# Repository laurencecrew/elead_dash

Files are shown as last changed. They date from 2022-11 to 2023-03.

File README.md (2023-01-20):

# elead_dash

Dash module for Honda Lead scooter electric conversion.

Based on STM32Duino for STM32F103C8T6

Design includes:
- Votol EM150SP 'CANbus' controller
- Daly R25A-GI02 BMS CANBus x 2
- SSD1306 OLED 64x48 0.66" SPI x 2
- Original fuel gauge driven by H-bridge / PWM
- See also, elead_lighting for tail light module

See 'Hardware' folder for:
- Bike wiring diagram
- PCB schematics
- Eagle files
- PCB CAM outputs

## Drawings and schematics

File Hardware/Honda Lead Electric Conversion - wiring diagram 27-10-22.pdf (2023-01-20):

## TO BATTERIES

1

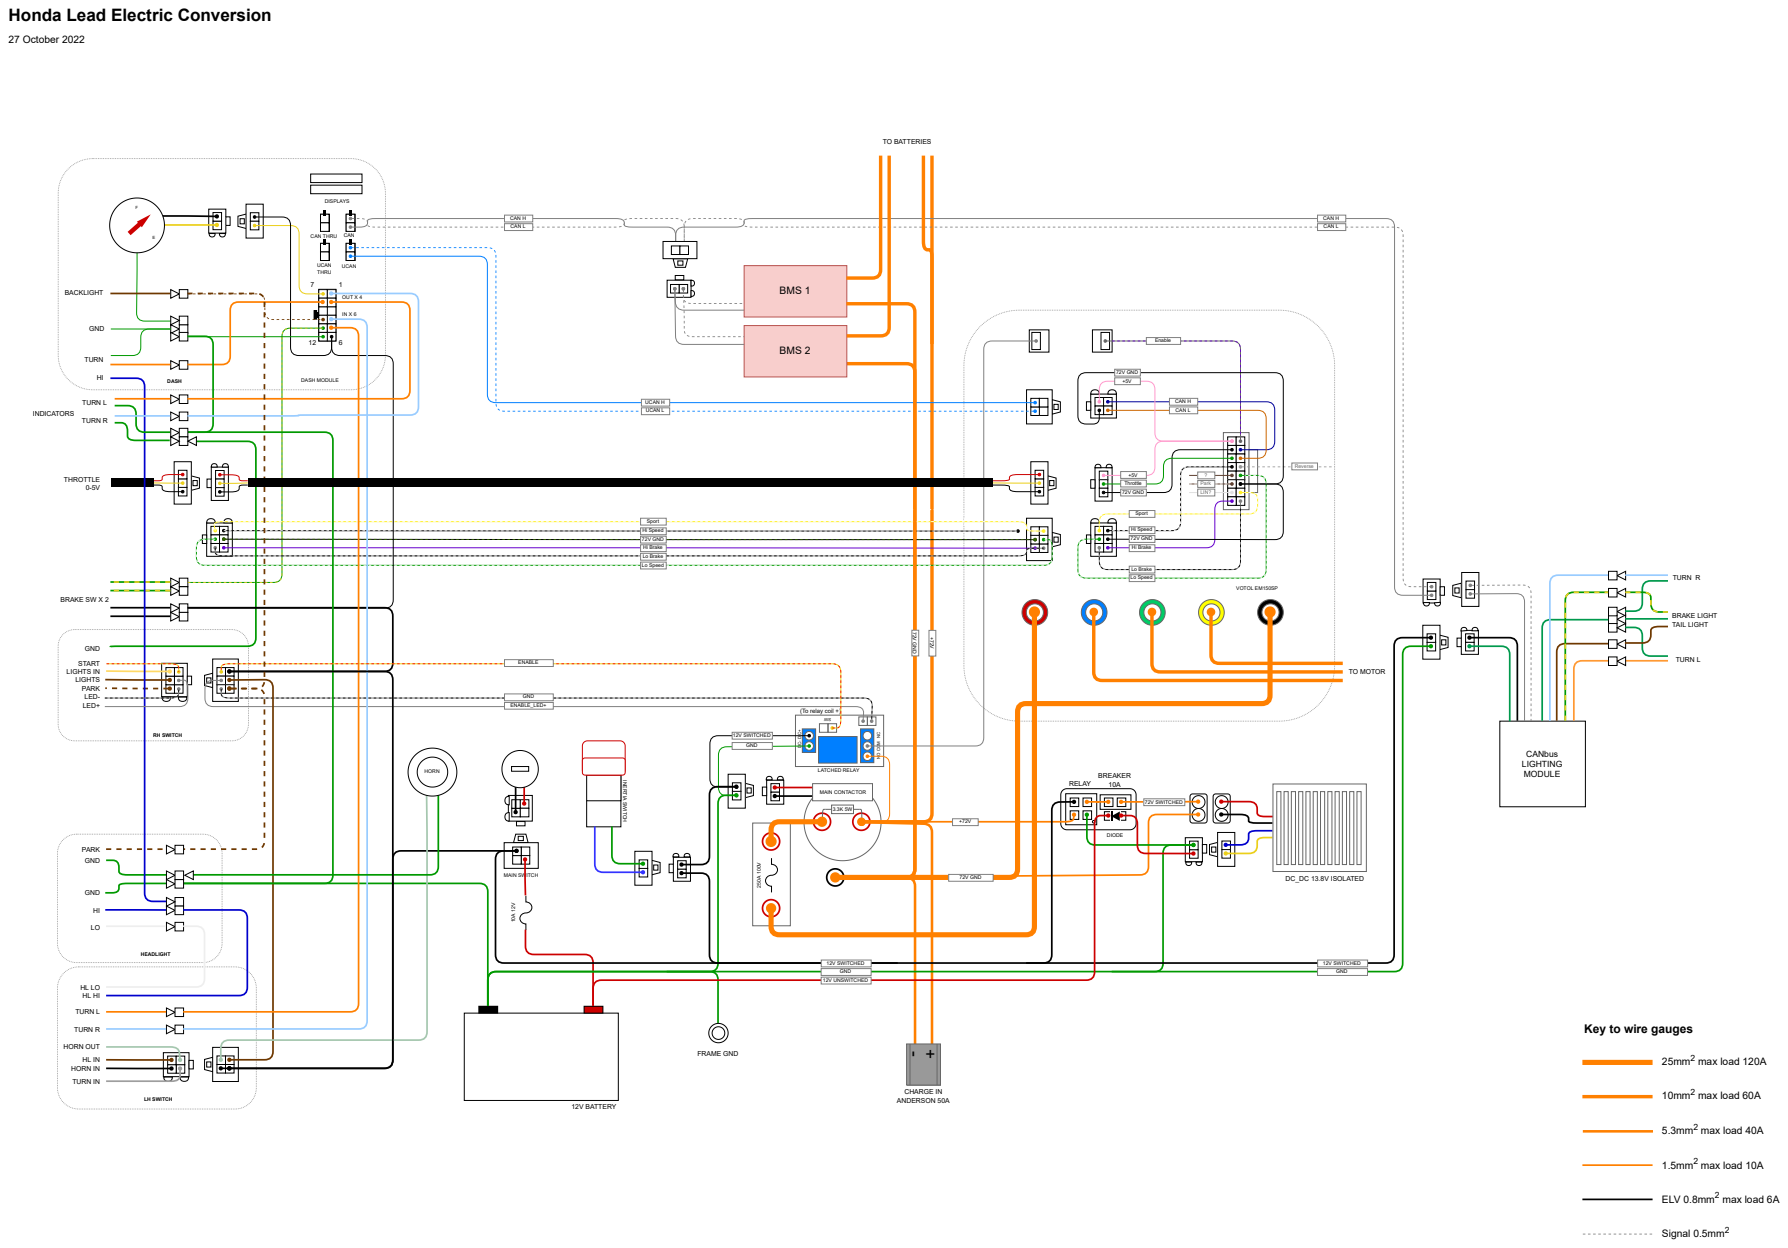
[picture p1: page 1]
RH SWITCH; Enable; Reverse; CAN H CAN L; 72V GND; Throttle; Sport; Lo Brake; ? Park; Hi Speed; LIN?; Lo Speed; Hi Brake; VOTOL EM150SP; DASH MODULE; MAIN CONTACTOR; TO MOTOR; CHARGE IN ANDERSON 50A; RELAY; LATCHED RELAY; DC_DC 13.8V ISOLATED; 12V SWITCHED; GND; 12V BATTERY; MAIN SWITCH; UCAN L; UCAN H; CAN L; CAN H; FRAME GND; CAN THRU; BRAKE SW X 2; Hi Brake Lo Brake Lo Speed; DIODE; 72V SWITCHED; ENABLE_LED+; HEADLIGHT; LH SWITCH; TURN L; TURN R; HORN OUT; TURN IN; HORN IN; PARK GND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

Honda Lead Electric Conversion

(To relay coil +)

NO COM NC

Key to wire gauges

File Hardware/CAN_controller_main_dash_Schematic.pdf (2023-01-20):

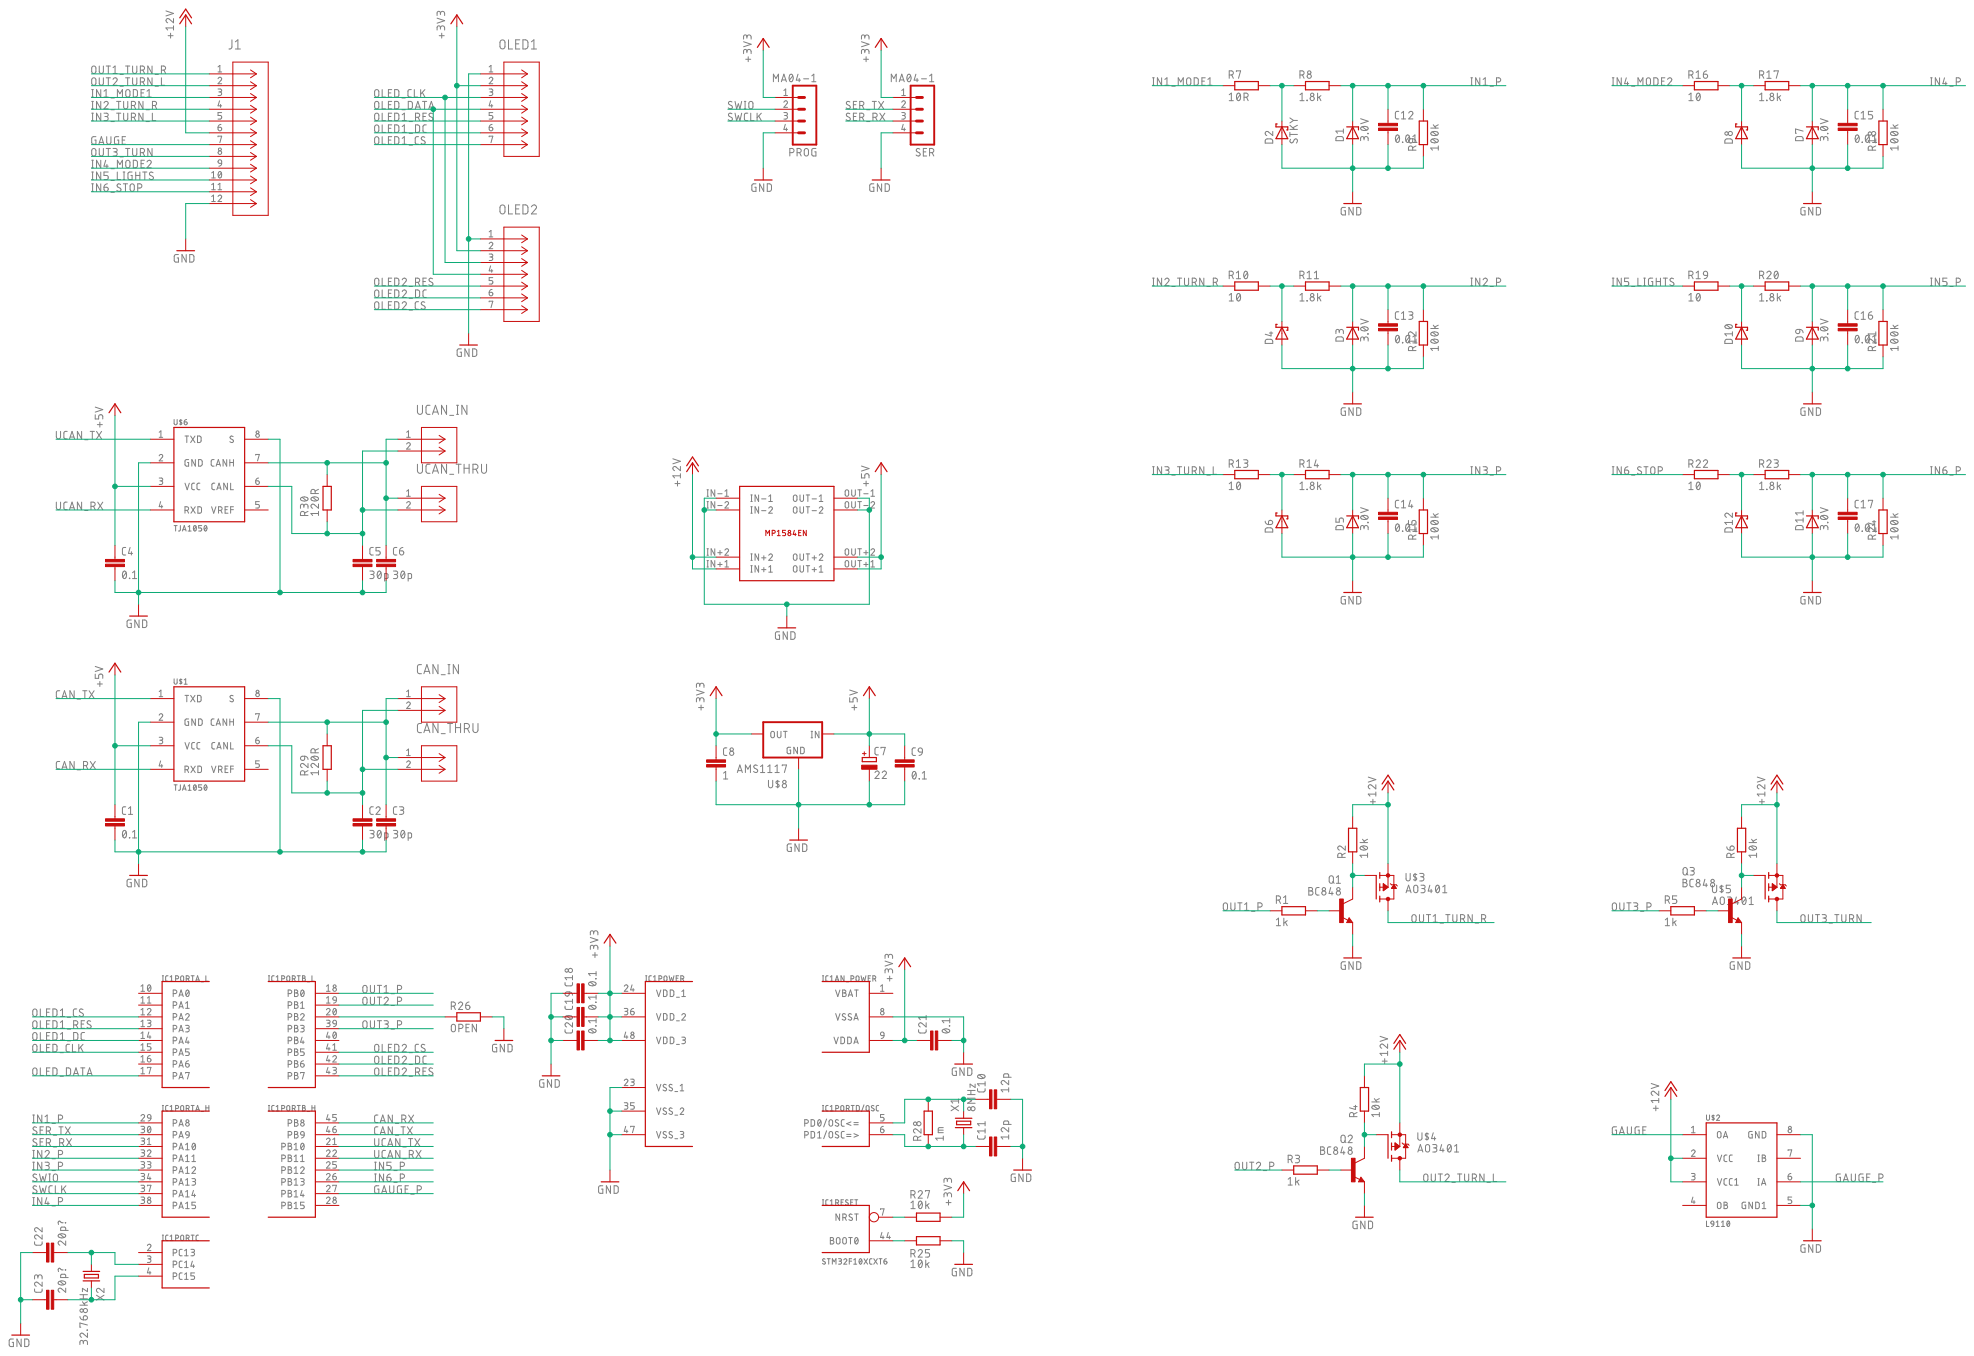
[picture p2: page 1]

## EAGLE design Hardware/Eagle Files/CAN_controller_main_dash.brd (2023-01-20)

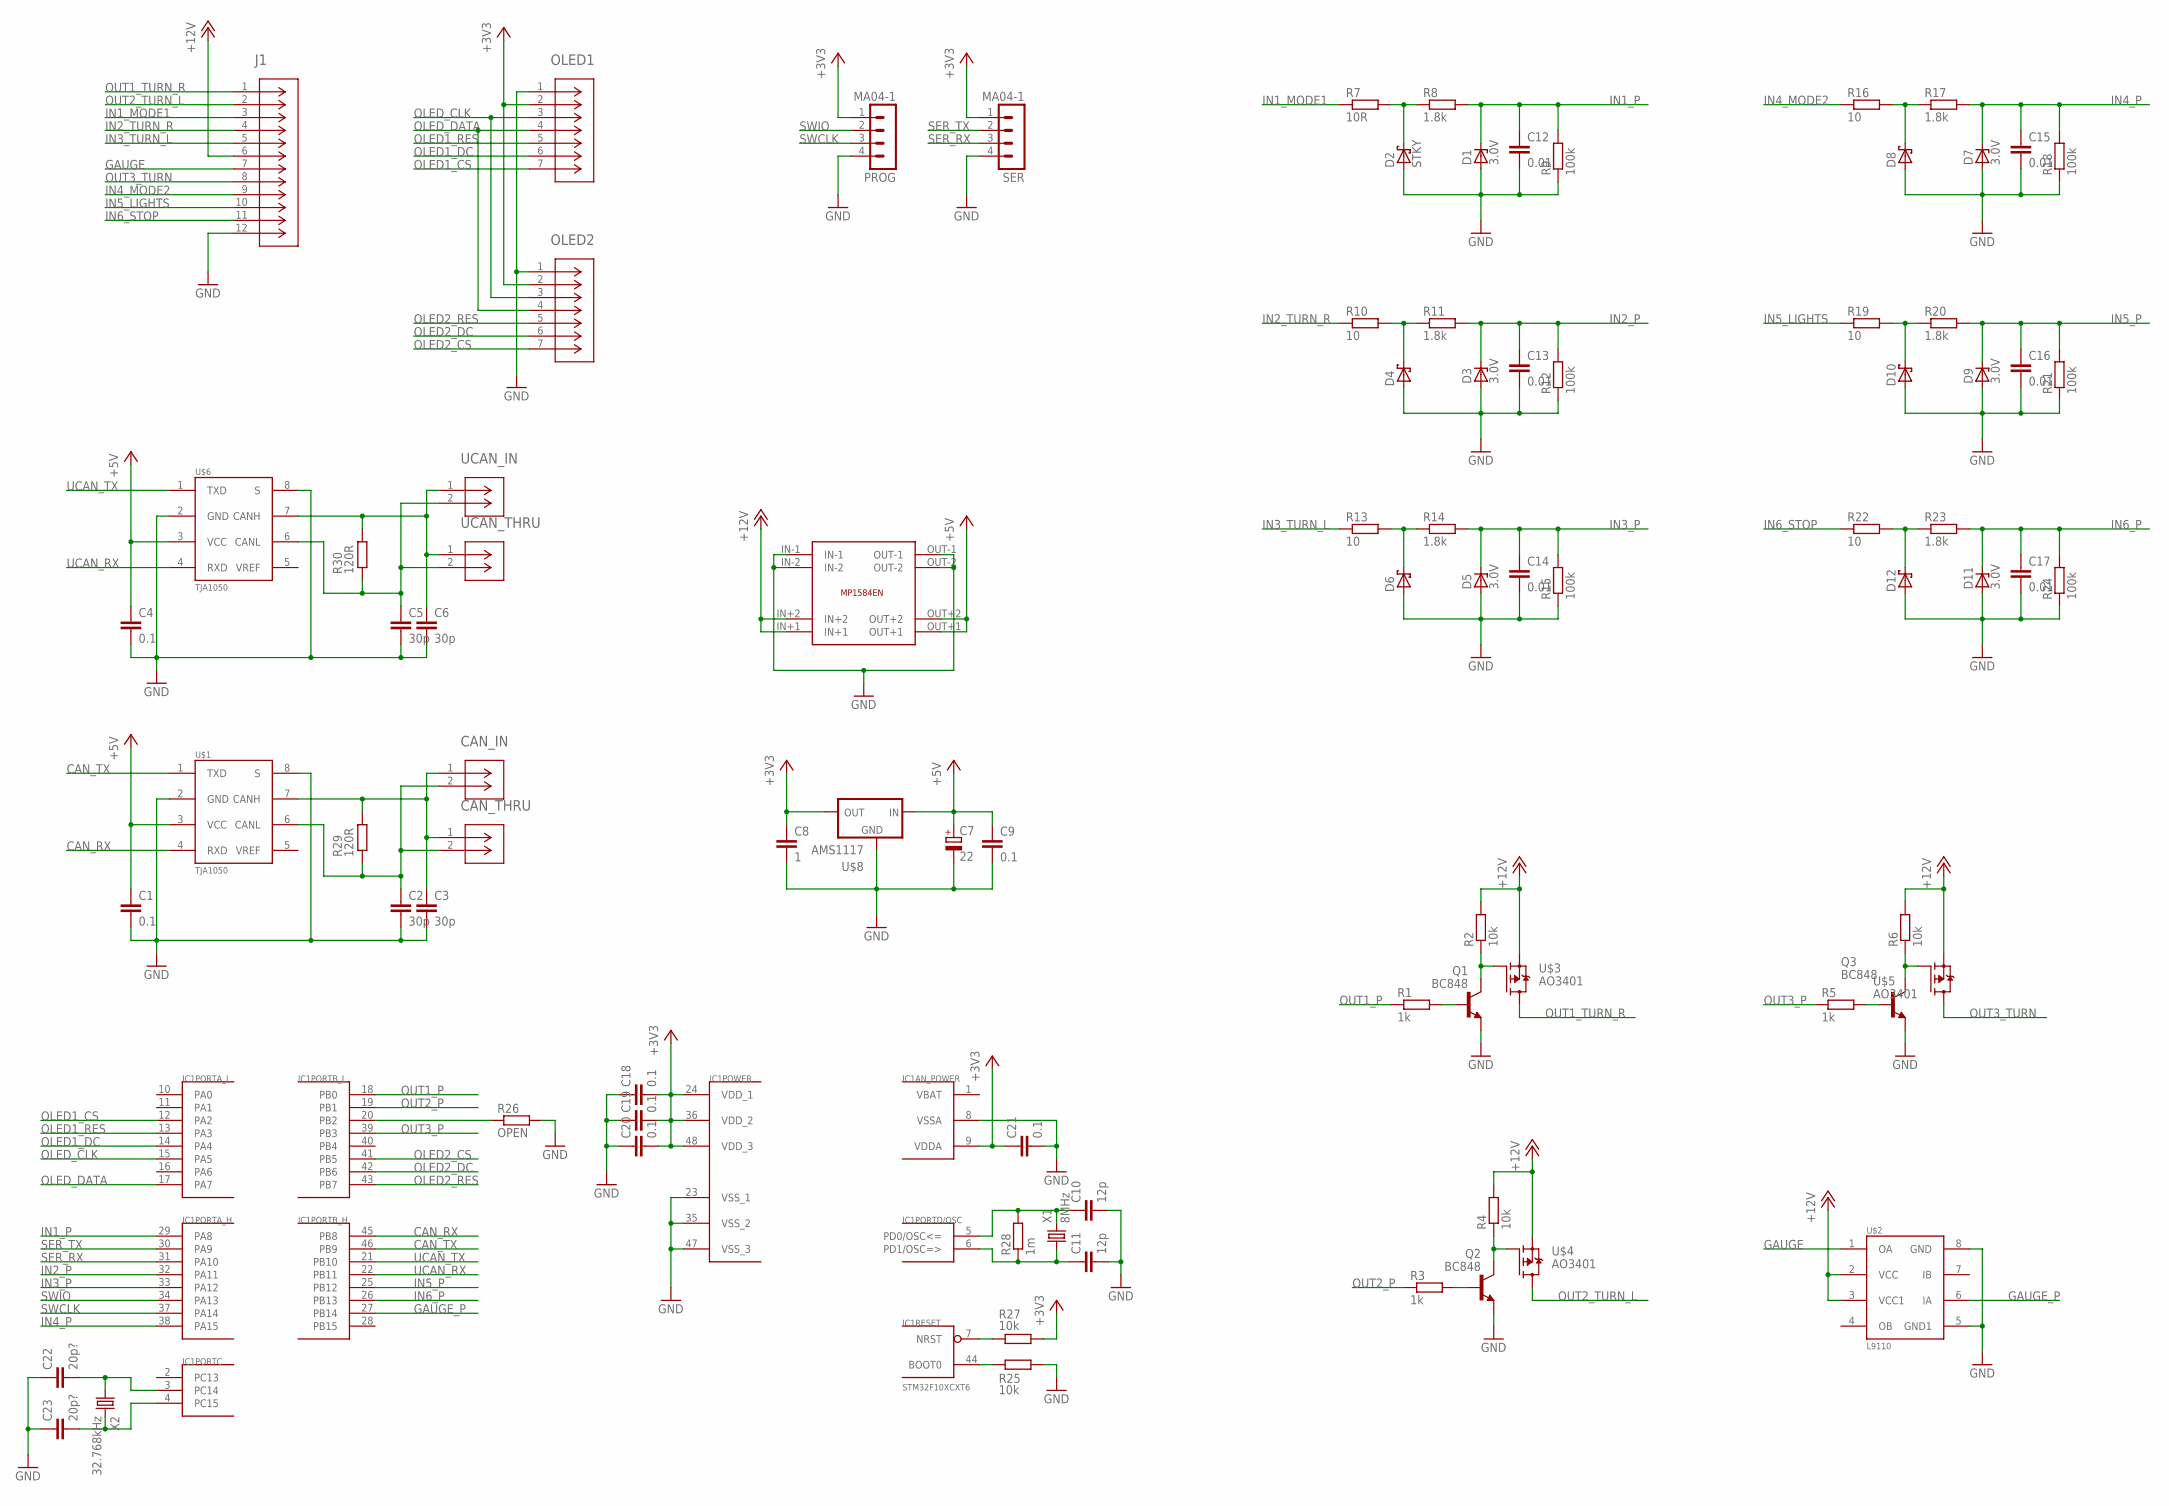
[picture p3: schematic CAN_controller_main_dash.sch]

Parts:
C1, C4, C9, C18, C19, C20, C21: 0.1; C0603
C2, C3, C5, C6: 30p; C0603
C7: 22; A/3216-18R
C8: 1; C0805
C10, C11: 12p; C0603
C12, C13, C14, C15, C16, C17: 0.01; C0603
C22, C23: 20p?; C0603
CAN_IN: CAN_IN; CON_2068320202_MOL
CAN_THRU: MOLEX_2068320202; CON_2068320202_MOL
D1, D3, D5, D7, D9, D11: 3.0V; ZD0603
D2: STKY; ZD0603
D4, D6, D8, D10, D12: DIODE_SCHOTTKY; ZD0603
IC1: STM32F10XCXT6; TQFP48
J1: MOLEX_2068321202; CON_2068321202_MOL
OLED1, OLED2: MOLEX_1053091107; CON_1053091107
PROG: MA04-1; 1X04
Q1, Q2, Q3: BC848; SOT23
R1, R3, R5: 1k; R0603
R2, R4, R6, R25, R27: 10k; R0603
R7: 10R; R0603
R8, R11, R14, R17, R20, R23: 1.8k; R0603
R9, R12, R15, R18, R21, R24: 100k; R0603
R10, R13, R16, R19, R22: 10; R0603
R26: OPEN; R0603
R28: 1m; R0603
R29, R30: 120R; R0603
SER: MA04-1; 1X04
U$1, U$6: TJA1050; SO08
U$2: L9110; SO08
U$3, U$4, U$5: AO3401; SOT23
U$7: MP1584_DC-DC_MODULEMINI_22X17; MP1584_DC-DC_MODULE
U$8: AMS1117; SOT223-W
UCAN_IN: MOLEX_2068320202; CON_2068320202_MOL
UCAN_THRU: MOLEX_2068320202; CON_2068320202_MOL
X1: 8MHz; XTAL-ECX-53
X2: 32.768kHz; MM20SS

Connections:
+3V3: C8.1, C18.2, C19.2, C20.2, C21.1, IC1.9 (VDDA), IC1.24 (VDD_1), IC1.36 (VDD_2), IC1.48 (VDD_3), OLED1.2, OLED2.2, PROG.1, R27.2, SER.1, U$8.2 (OUT)
+5V: C1.1, C4.1, C7.+, C9.1, U$1.3 (VCC), U$6.3 (VCC), U$7.OUT+1, U$7.OUT+2, U$8.3 (IN)
+12V: J1.6, R2.2, R4.2, R6.2, U$2.2 (VCC), U$2.3 (VCC1), U$3.2 (S), U$4.2 (S), U$5.2 (S), U$7.IN+1, U$7.IN+2
CANH: C3.1, CAN_IN.1, CAN_THRU.1, R29.2, U$1.7 (CANH)
CANL: C2.1, CAN_IN.2, CAN_THRU.2, R29.1, U$1.6 (CANL)
CAN_RX: IC1.45 (PB8), U$1.4 (RXD)
CAN_TX: IC1.46 (PB9), U$1.1 (TXD)
GAUGE: J1.7, U$2.1 (OA)
GAUGE_P: IC1.27 (PB14), U$2.6 (IA)
GND: C1.2, C2.2, C3.2, C4.2, C5.2, C6.2, C7.-, C8.2, C9.2, C10.2, C11.2, C12.2, C13.2, C14.2, C15.2, C16.2, C17.2, C18.1, C19.1, C20.1, C21.2, C22.1, C23.1, D1.A, D2.A, D3.A, D4.A, D5.A, D6.A, D7.A, D8.A, D9.A, D10.A, D11.A, D12.A, IC1.8 (VSSA), IC1.23 (VSS_1), IC1.35 (VSS_2), IC1.47 (VSS_3), J1.12, OLED1.1, OLED2.1, PROG.4, Q1.2 (E), Q2.2 (E), Q3.2 (E), R9.1, R12.1, R15.1, R18.1, R21.1, R24.1, R25.2, R26.2, SER.4, U$1.2 (GND), U$1.8 (S), U$2.5 (GND1), U$2.8 (GND), U$6.2 (GND), U$6.8 (S), U$7.IN-1, U$7.IN-2, U$7.OUT-1, U$7.OUT-2, U$8.1 (GND)
IN1_MODE1: J1.3, R7.1
IN1_P: C12.1, D1.C, IC1.29 (PA8), R8.2, R9.2
IN2_P: C13.1, D3.C, IC1.32 (PA11), R11.2, R12.2
IN2_TURN_R: J1.4, R10.1
IN3_P: C14.1, D5.C, IC1.33 (PA12), R14.2, R15.2
IN3_TURN_L: J1.5, R13.1
IN4_MODE2: J1.9, R16.1
IN4_P: C15.1, D7.C, IC1.38 (PA15), R17.2, R18.2
IN5_LIGHTS: J1.10, R19.1
IN5_P: C16.1, D9.C, IC1.25 (PB12), R20.2, R21.2
IN6_P: C17.1, D11.C, IC1.26 (PB13), R23.2, R24.2
IN6_STOP: J1.11, R22.1
unnamed: Q2.1 (B), R3.2
unnamed: Q2.3 (C), R4.1, U$4.1 (G)
unnamed: Q3.1 (B), R5.2
unnamed: Q1.1 (B), R1.2
unnamed: Q1.3 (C), R2.1, U$3.1 (G)
unnamed: Q3.3 (C), R6.1, U$5.1 (G)
unnamed: C10.1, IC1.5 (PD0/OSC<=), R28.2, X1.2
unnamed: C11.1, IC1.6 (PD1/OSC=>), R28.1, X1.1
unnamed: D2.C, R7.2, R8.1
unnamed: IC1.44 (BOOT0), R25.1
unnamed: D4.C, R10.2, R11.1
unnamed: IC1.20 (PB2), R26.1
unnamed: IC1.7 (NRST), R27.1
unnamed: D6.C, R13.2, R14.1
unnamed: C22.2, IC1.3 (PC14), X2.1
unnamed: C23.2, IC1.4 (PC15), X2.4 (2)
unnamed: D8.C, R16.2, R17.1
unnamed: D10.C, R19.2, R20.1
unnamed: D12.C, R22.2, R23.1
OLED1_CS: IC1.12 (PA2), OLED1.7
OLED1_DC: IC1.14 (PA4), OLED1.6
OLED1_RES: IC1.13 (PA3), OLED1.5
OLED2_CS: IC1.41 (PB5), OLED2.7
OLED2_DC: IC1.42 (PB6), OLED2.6
OLED2_RES: IC1.43 (PB7), OLED2.5
OLED_CLK: IC1.15 (PA5), OLED1.3, OLED2.3
OLED_DATA: IC1.17 (PA7), OLED1.4, OLED2.4
OUT1_P: IC1.18 (PB0), R1.1
OUT1_TURN_R: J1.1, U$3.3 (D)
OUT2_P: IC1.19 (PB1), R3.1
OUT2_TURN_L: J1.2, U$4.3 (D)
OUT3_P: IC1.39 (PB3), R5.1
OUT3_TURN: J1.8, U$5.3 (D)
SER_RX: IC1.31 (PA10), SER.3
SER_TX: IC1.30 (PA9), SER.2
SWCLK: IC1.37 (PA14), PROG.3
SWIO: IC1.34 (PA13), PROG.2
UCANH: C6.1, R30.2, U$6.7 (CANH), UCAN_IN.1, UCAN_THRU.1
UCANL: C5.1, R30.1, U$6.6 (CANL), UCAN_IN.2, UCAN_THRU.2
UCAN_RX: IC1.22 (PB11), U$6.4 (RXD)
UCAN_TX: IC1.21 (PB10), U$6.1 (TXD)
VBAT: IC1.1 (VBAT)

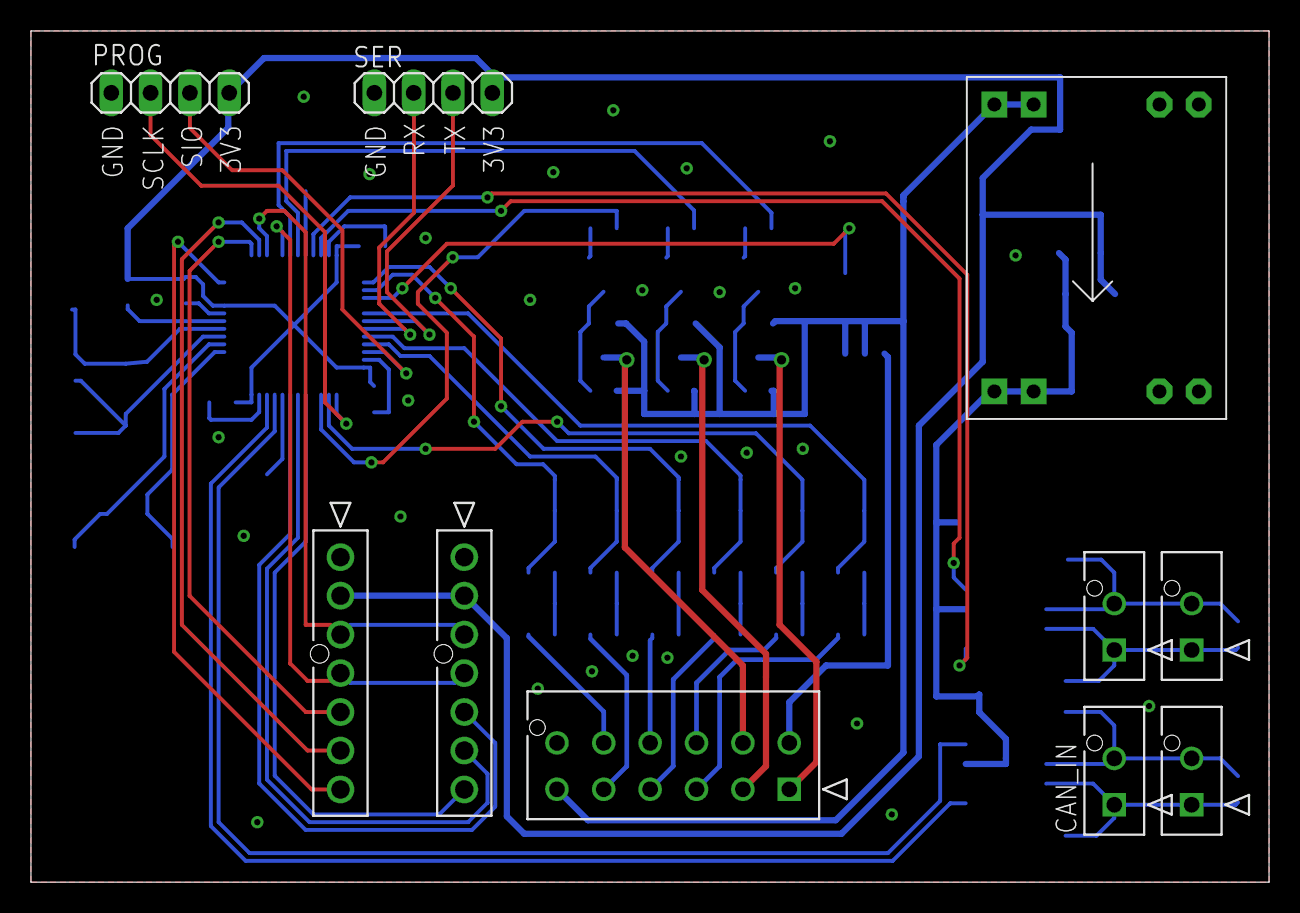
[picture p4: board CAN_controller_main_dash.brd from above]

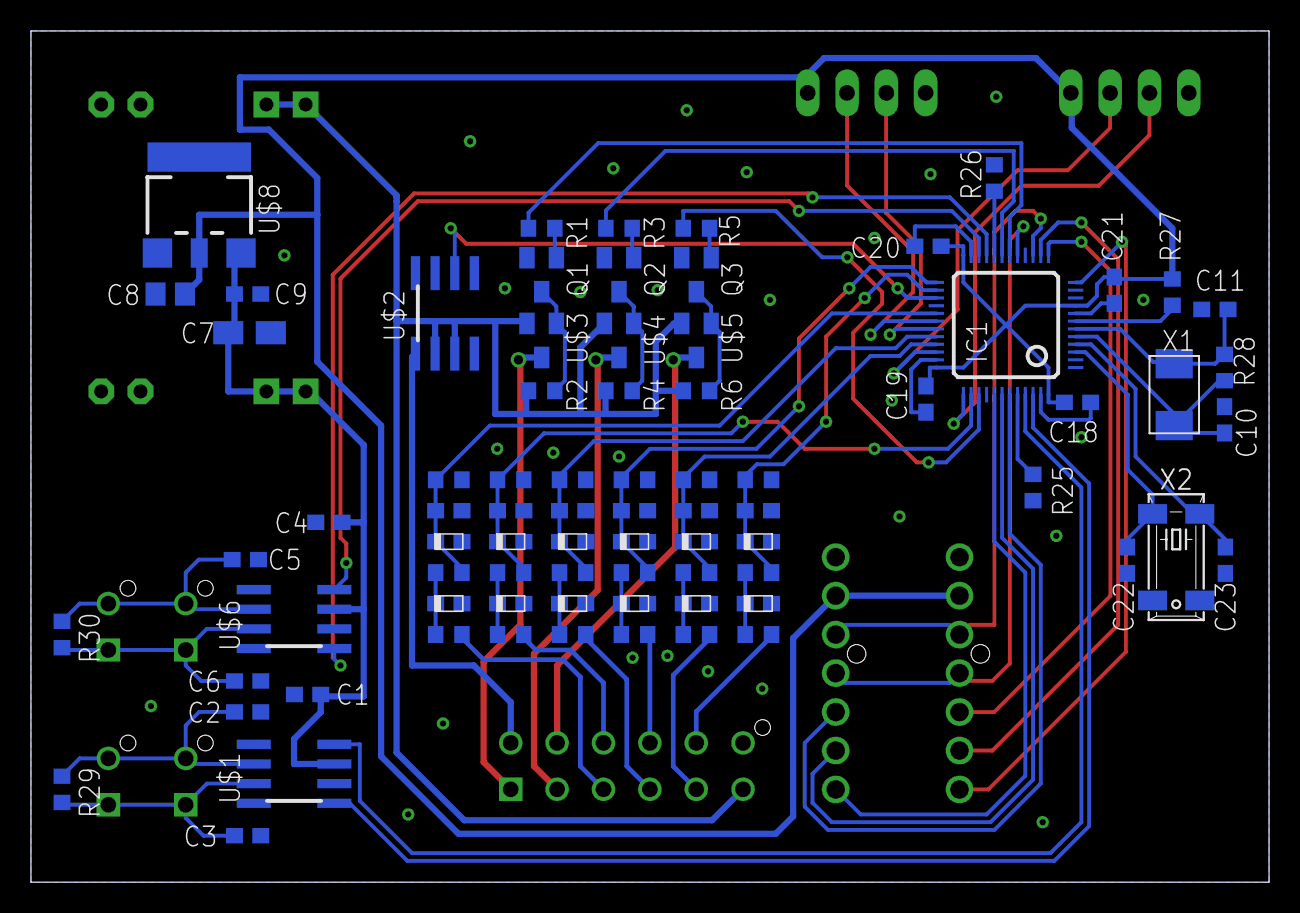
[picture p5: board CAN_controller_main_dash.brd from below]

Board: 2 copper layers, 80.0 x 55.0 mm, 88 parts (78 on the bottom side), 63 nets.

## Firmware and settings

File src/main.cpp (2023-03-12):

/* 
  Honda Lead Electric conversion dash module
  - Read data from Daly BMS and Votol controller, show on OLED displays and fuel gauge
  - Control indicator, brake and tail lights via CANBus
  - CAN driver code adapted from https://github.com/nopnop2002/Arduino-STM32-CAN
  - Use included version of library adafruit/Adafruit SSD1306@^2.5.1 as it has bug fixes / adaptations
  laurence@laurencecrew.com 2022
*/

#include <Arduino.h>
#include "pins.h"
#include "debug.h"
#include "timers.h"
#include "can.h"
#include "display.h"
#include "dalybms.h"
#include "votol_em.h"
#include "can_lights.h"
#include "gauge.h"
#include "trip_stats.h"

// blink states for turn indicators
#define BLINK_MODE_NONE       0
#define BLINK_MODE_LEFT       1
#define BLINK_MODE_RIGHT      2

// operational states
#define STATE_STARTING        0 // no real data yet
#define STATE_IDLE            1 // controller off
#define STATE_WAKEUP          2 // controller waking up
#define STATE_ACTIVE          3 // controller on
#define STATE_CHARGING        4 // charger connected
#define STATE_EXT_CONTROL     5 // external control software connected

// display modes
#define NUM_MODES             3 // count of ..
#define MODE_AMPS             0 // motor amps, real time
#define MODE_TRIP             1 // distance and time TODO
#define MODE_STATS            2 // Wh/km, avg km/h TODO

// timing
// NOTES Votol request / read takes ~5ms
//  BMS read takes 20/40/outlier 60ms to respond, generally <= 15ms for 2 packets
//  Screen update ~ 5ms
//  Votol parameter change 5 successive reads / 500ms
//  Votol software reads every ~100ms; RPM updates fast but current also ~500ms
#define T_TICK            50 // ms = base time / timer interrupt interval; also VOTOL spamming rate in IDLE
#define T_READ            250 / T_TICK // ticks; interval between reading BMS data and VOTOL data in ACTIVE state ALSO updating lights
#define T_VOTOL_TIMEOUT   750 / (T_READ * T_TICK) // Read cycles. If Votol does not respond (e.g. off), go to IDLE state
#define T_BLINK           500 / T_TICK // ticks; on-off blink time for turn indicators
#define T_DEBOUNCE        1000 // us; wait before reading inputs after interrupt 
#define T_CHARGE_TIMEOUT  10 // ticks in IDLE; successful reads in ACTIVE. If charge is detected, wait a few cycles before changing state to make sure


// Globals
volatile bool tick_flag = true; // true on start and every timer cycle
volatile uint8_t read_cnt = 0; // read every n tick cycles
volatile bool read_flag = true; // true on start and whenever a read is due
volatile bool debounce_flag = false; // whenever an input state changes
volatile bool update_lights_flag = true; // true on start and whenever lights are due for update
bool display_init = false; // false on start - make true if displays successfully initialise

volatile uint8_t state = STATE_STARTING;
uint8_t display_mode = MODE_AMPS;
//uint8_t display_mode = MODE_TRIP;
//uint8_t display_mode = MODE_STATS;

// Trip meter and stats
// TODO: Still implementing
int read_t;                   // time (ms) since last read
int last_read_t;              // time (ms) of last read

// keep track of which data has been updated on each read cycle
typedef union
{
  struct
  {
    bool votol:1;
    bool bms_soc_1:1;
    bool bms_temp_1:1;
    bool bms_fault_1:1;
    bool bms_charging_1:1;
    //bool bms_soc_2:1;
    //bool bms_temp_2:1;
    //bool bms_fault_2:1;
  } flags;

  uint8_t all_flags;

} Update_flags_t;
  
#define ALL_UPDATED 0b00011111 // votol and BMS 1
//#define ALL_UPDATED 0b01111111 // votol and BMS 1&2
#define BMS_UPDATED 0b0001110

Update_flags_t update_flags;

// Response packets and data buffers
uint8_t votol_timeout_cnt = 0;
uint8_t charge_timeout_cnt = 0;

// turn signal blinking mode & states
uint8_t blink_mode = BLINK_MODE_NONE, last_blink_mode = BLINK_MODE_NONE;
volatile bool blink_state = false;
volatile uint8_t blink_count = 0;

// function prototypes
void init_dash ();
void update_lights ();

// interrupt handlers
void input_ISR ();
void tick ();

// Get started .. 
void setup ()
{

  // Initialise all pins
  pinMode (LIGHTS_IN, INPUT);
  pinMode (TURN_L_IN, INPUT);
  pinMode (TURN_R_IN, INPUT);
  pinMode (BRAKE_IN, INPUT);
  pinMode (MODE_1_IN, INPUT);
  pinMode (MODE_2_IN, INPUT);

  // Put gauge output pin into a neutral(?) state prior to starting PWM later
  // Doesn't really work as the H-bridge only has H and L states
  // Pulling HIGH as an output makes the gauge drop; otherwise it rises on startup
  pinMode (GAUGE_PWM, INPUT_FLOATING);

  // Input pin interrupts
  // capture any change to lights; falling for mode switch
  //attachInterrupt (digitalPinToInterrupt (LIGHTS_IN), input_ISR, CHANGE); // NOTE: Can't use PB12 and PA12 interrupts as they are on the same 'line' :/
  attachInterrupt (digitalPinToInterrupt (TURN_L_IN), input_ISR, CHANGE);
  attachInterrupt (digitalPinToInterrupt (TURN_R_IN), input_ISR, CHANGE);
  attachInterrupt (digitalPinToInterrupt (BRAKE_IN), input_ISR, CHANGE);
  attachInterrupt (digitalPinToInterrupt (MODE_1_IN), input_ISR, RISING);
  //attachInterrupt (digitalPinToInterrupt (MODE_2_IN), input_ISR, FALLING); // For future mode switch

  pinMode (TURN_L_OUT, OUTPUT);
  pinMode (TURN_R_OUT, OUTPUT);
  pinMode (TURN_IND_OUT, OUTPUT);

  digitalWrite (TURN_L_OUT, LOW);
  digitalWrite (TURN_R_OUT, LOW);
  digitalWrite (TURN_IND_OUT, LOW);
  
  // clear data buffers - no junk data
  // may not need this now with state machine? Doesn't hurt
  memcpy (&VOTOL_Response.data, &VOTOL_Buffer_init, sizeof (VOTOL_Buffer_init));

  // TODO: Move this to an init function in votol module?
  VotolSerial.begin (VOTOL_UART_BAUD);

  #ifdef DEBUG
    DebugSerial.begin (115200);
    DebugSerial.println ("Starting ..");
  #endif

  // initialise hardware timer - SetInterval etc
  TMR_Init();

  // initialise dash (start OLEDs, gauge)
  init_dash ();

  #ifdef DEBUG
    DebugSerial.println ("Init CAN ..");
  #endif

  // initialise CAN
  bool ret = CANInit(CAN_250KBPS, CAN_REMAP);  // CAN_RX mapped to PB8, CAN_TX mapped to PB9
  if (!ret) while(true);

  #ifdef DEBUG
    DebugSerial.println ("Done!");
  #endif

  update_flags.all_flags = 0; // reset flags

  // update the lights on start
  // note; need to do this after CAN is initialised
  update_lights ();

  // initialise trip stats
  // in particular, start the RTC
  // note time is set to 0 on entering ACTIVE state
  TRIP_STATS_init ();

  delay (500); // wait a bit for everthing to settle

  // start tick timer
  TMR_SetInterval (tick, T_TICK);

}

void loop()
{
  CAN_msg_t CAN_RX_msg;
  
  // lights need to be updated ..
  if (update_lights_flag)
  {
    update_lights_flag = false; // reset
    update_lights();
  }

  // debounce = input state has changed e.g. light switches, mode in
  if (debounce_flag)
  {
      debounce_flag = false; // reset

      // TODO: Save return state after debounce?
      delayMicroseconds (T_DEBOUNCE);

      // re-enable interrupts NOTE buggy
      // after disabling them in Input_ISR
      // note, do this before update_lights as it is probably needed for CAN comms
      // TODO may need to clear queued interrupts?
      //interrupts();

      // Loop display modes on MODE_1_IN
      if (digitalRead (MODE_1_IN) == HIGH) // still high after interrupt & debounce
      {
          // loop modes
          if (++display_mode >= NUM_MODES)
            display_mode = 0;
      }
  
      // update lights in case any state has changed
      update_lights();

  }

  // Check for data on VOTOL "CAN" UART
  // If in External Control state, just ignore it
  // otherwise hard buffer flush disturbs communications
  if (state != STATE_EXT_CONTROL && VotolSerial.available())
  { 
    VotolSerial.readBytes(VOTOL_Buffer, sizeof VOTOL_Response.data);

    // if successful / valid packet
    if (VOTOL_check_response (VOTOL_Buffer))
    {
      memcpy (&VOTOL_Response.data, &VOTOL_Buffer, sizeof (VOTOL_Response.data));
      update_flags.flags.votol = true;
      votol_timeout_cnt = 0;

      #ifdef DEBUG
      /*
        DebugSerial.print ("Controller Volts: ");
        DebugSerial.println (VOTOL_get_volts (&VOTOL_Response.resp));
        DebugSerial.print ("Controller Amps: ");
        DebugSerial.println (VOTOL_get_amps (&VOTOL_Response.resp));
        DebugSerial.print ("Motor Temp: ");
        DebugSerial.println (VOTOL_get_motor_temp (&VOTOL_Response.resp));
        DebugSerial.print ("RPM: ");
        DebugSerial.println (VOTOL_get_rpm (&VOTOL_Response.resp));
        DebugSerial.print ("Cont status 2: ");
        DebugSerial.println (VOTOL_Response.resp.status_2, HEX);
        DebugSerial.print ("Controller status 1: ");
        DebugSerial.println (VOTOL_Response.resp.status_1, HEX);
        DebugSerial.print ("Regen: ");
        DebugSerial.println (VOTOL_get_regen_status (&VOTOL_Response.resp));
        DebugSerial.print ("Controller Temp: ");
        DebugSerial.println (VOTOL_get_contr_temp (&VOTOL_Response.resp));
      */
      #endif
    }
    else if (VOTOL_check_external_read (VOTOL_Buffer))
    {
      // check for external software trying to connect
      // if so, suppress data reading until next restart

      // Enter external control state until next power cycle
      state = STATE_EXT_CONTROL;

      // update display to show connect mode
      draw_display (display1, DISPLAY_MODE_CONNECT, NULL, NULL, NULL, NULL, NULL);
      draw_display (display2, DISPLAY_MODE_CONNECT, NULL, NULL, NULL, NULL, NULL);

      #ifdef DEBUG
        DebugSerial.print ("To state: EXT_CONTROL");
      #endif
    }
    else
    {
      #ifdef DEBUG

        DebugSerial.println ("Bad Votol packet! Flushing ..");

        //dump the data & clear as I go
        DebugSerial.print ("Data: ");
        for (int j=0; j < sizeof (VOTOL_Buffer); j++)
        {
          DebugSerial.printf ("%x ", VOTOL_Buffer[j]);
          VOTOL_Buffer[j] = 0;
        }
        DebugSerial.println("");
              
      #endif

      // flush any remaining data
      VOTOL_flush_rx ();

    }
  }

  // Check for CAN data from BMS(s)
  if(CANMsgAvail())
  {
    CANReceive(&CAN_RX_msg);

    if (CAN_RX_msg.id == BMS_ParseId (BMS_soc_id_1))
    {
      // get data from the CAN packet into the report structure
      memcpy(&BMS_rpt_soc_1, CAN_RX_msg.data, sizeof BMS_rpt_soc_1);
      update_flags.flags.bms_soc_1 = true;

      /*
      #ifdef DEBUG
        DebugSerial.print ("SOC 1: ");
        DebugSerial.println (BMS_get_soc (&BMS_rpt_soc_1));
        DebugSerial.print ("Volts 1: ");
        DebugSerial.println (BMS_get_volts (&BMS_rpt_soc_1));
        DebugSerial.print ("Amps 1: ");
        DebugSerial.println (BMS_get_amps (&BMS_rpt_soc_1));
      #endif
      */
    }
    else if (CAN_RX_msg.id == BMS_ParseId (BMS_temp_id_1))
    {
      // get data from the CAN packet into the report structure
      memcpy(&BMS_rpt_temp_1, CAN_RX_msg.data, sizeof BMS_rpt_temp_1);
      update_flags.flags.bms_temp_1 = true;

      /*
      #ifdef DEBUG
        DebugSerial.print ("Temp 1: ");
        DebugSerial.println (BMS_get_temp(&BMS_rpt_temp_1));
      #endif
      */
    }
    /* don't need this one for now
    else if (CAN_RX_msg.id == BMS_ParseId (BMS_status_id_1))
    {
      // get data from the CAN packet into the report structure
      memcpy(&BMS_rpt_status_1, CAN_RX_msg.data, sizeof BMS_rpt_status_1);
      //update_flags.flags.bms_status_1 = true;

      #ifdef DEBUG
        DebugSerial.print ("Status charger_status: ");
        DebugSerial.println (BMS_rpt_status_1.charger_status);
        DebugSerial.print ("Status load_status: ");
        DebugSerial.println (BMS_rpt_status_1.load_status);
      #endif
    }*/
    else if (CAN_RX_msg.id == BMS_ParseId (BMS_charging_id_1))
    {
      // get data from the CAN packet into the report structure
      memcpy(&BMS_rpt_charging_1, CAN_RX_msg.data, sizeof BMS_rpt_charging_1);
      update_flags.flags.bms_charging_1 = true;

      #ifdef DEBUG
        //DebugSerial.print ("Charging charge_status: ");
        //DebugSerial.println (BMS_rpt_charging_1.charge_status);
      #endif
    }
    else if (CAN_RX_msg.id == BMS_ParseId (BMS_fault_id_1))
    {
      // get data from the CAN packet into the report structure
      memcpy(&BMS_rpt_fault_1, CAN_RX_msg.data, sizeof BMS_rpt_fault_1);
      update_flags.flags.bms_fault_1 = true;

      #ifdef DEBUG
        DebugSerial.print ("Fault 1: ");
        DebugSerial.println (BMS_rpt_fault_1.byte_7);
      #endif
    }
    
    /* If I can get the CAN ID changed on the 2nd BMS .. 
    else if (CAN_RX_msg.id == BMS_ParseId (BMS_soc_id_2))
    {
      // get data from the CAN packet into the report structure
      memcpy(&BMS_rpt_soc_2, CAN_RX_msg.data, sizeof BMS_rpt_soc_2);
      update_flags.flags.bms_soc_2 = true;
    }
    else if (CAN_RX_msg.id == BMS_ParseId (BMS_temp_id_2))
    {
      // get data from the CAN packet into the report structure
      memcpy(&BMS_rpt_temp_2, CAN_RX_msg.data, sizeof BMS_rpt_temp_2);
      update_flags.flags.bms_temp_2 = true;
    }
    else if (CAN_RX_msg.id == BMS_ParseId (BMS_fault_id_2))
    {
      // get data from the CAN packet into the report structure
      memcpy(&BMS_rpt_fault_2, CAN_RX_msg.data, sizeof BMS_rpt_fault_2);
      update_flags.flags.bms_fault_2 = true;
    } 
    */
  }

  /* state machine coding principles
  - process transitions first
  - reset each update flag as it is 'used'
  - read data as needed in the state
  */

  // State dependent updates to display etc
  switch (state)
  {
    // no valid data yet
    case STATE_STARTING:

      // got valid data from BMS:
      if (update_flags.flags.bms_soc_1)
      {
        // clear the flag
        update_flags.flags.bms_soc_1 = false;

        // start the gauge & update it
        GAUGE_Init();
        GAUGE_Set (BMS_get_soc (&BMS_rpt_soc_1));

        state = STATE_IDLE;

        #ifdef DEBUG
          DebugSerial.println("To state: IDLE");
        #endif
      }

    break;

    // BMS is sending data but Votol controller is off
    case STATE_IDLE:

      // got valid data from Votol: progress to WAKEUP
      if (update_flags.flags.votol)
      {
        // clear the flag
        update_flags.flags.votol = false;

        // wait for controller to wake up
        state = STATE_WAKEUP;

        // next read
        VotolSerial.write (VOTOL_Request_Local, sizeof (VOTOL_Request_Local));

        // immediately read / clear the buffer
        // as the 'CAN' converter echos the TX packet back to RX
        // Flush instead of reading back to avoid hanging on corrupted packets
        //VotolSerial.readBytes (VOTOL_Buffer, sizeof (VOTOL_Request_Local));
        VOTOL_flush_rx ();

        #ifdef DEBUG
          DebugSerial.println("To state: WAKEUP");
        #endif
      }
      else if (tick_flag)
      {
        tick_flag = false;

        // Spam the VOTOL controller to stop it sending its own requests on startup (causing a delay)
        // do this on every timer tick

        #ifdef DEBUG
          DebugSerial.println ("Spamming Votol");
        #endif
        
        // TODO: Consider testing availableForWrite()? Returns available space in buffer

        // Request data from motor controller via UART
        VotolSerial.write (VOTOL_Request_Local, sizeof (VOTOL_Request_Local));

        // immediately read / clear the buffer
        // as the 'CAN' converter echos the TX packet back to RX
        // When controller first starts, it interrupts the outgoing packet, losing 1 byte
        // This causes a hang if waiting for a complete request to be read back
        // So, flush the buffer instead
        VOTOL_flush_rx ();

        #ifdef DEBUG
          //DebugSerial.println ("Readback done");
        #endif
      }

      // get data from BMS only and update the dash
      if ((update_flags.all_flags & BMS_UPDATED) == BMS_UPDATED)
      {
        update_flags.all_flags &= ~BMS_UPDATED; // reset update flags for next time

        // If charging detected whilst Votol disabled (no need to check for regen charging)rge_timeout_cnt?
        if (BMS_get_charge_status (&BMS_rpt_charging_1))
        {
          if (++charge_timeout_cnt >= T_CHARGE_TIMEOUT) // count a few times to make sure
          {
            charge_timeout_cnt = 0; // reset for next time

            state = STATE_CHARGING;

            #ifdef DEBUG
              DebugSerial.println("To state: CHARGING");
            #endif
          }
        }
        else
        {
          // not charging, reset the counter
          charge_timeout_cnt = 0;
        }

        #ifdef DEBUG
          DebugSerial.println ("Updating dash");
        #endif

        // Display 1 content according to mode
        switch (display_mode)
        {
          case MODE_AMPS:
            draw_display (display1, DISPLAY_MODE_AMPS, NULL, NULL, NULL, NULL, NULL);
            break;

          case MODE_TRIP:
            draw_display (display1, DISPLAY_MODE_TRIP, NULL, NULL, NULL, NULL, NULL);
            break;

          case MODE_STATS:
            draw_display (display1, DISPLAY_MODE_STATS, NULL, NULL, NULL, NULL, NULL);
            break;
        }

        draw_display (display2, DISPLAY_MODE_TEMPS, NULL, &BMS_rpt_soc_1, &BMS_rpt_temp_1, &BMS_rpt_fault_1, NULL);
        GAUGE_Set (BMS_get_soc (&BMS_rpt_soc_1));
      }

    break;

    // waiting for controller to wake up
    // as it tends to send junk data for a little while
    // e.g. temperature 96C
    case STATE_WAKEUP:

      if (update_flags.flags.votol)
      {
        // clear the flag
        update_flags.flags.votol = false;

        if (VOTOL_check_valid_temp (&VOTOL_Response.resp))
        {
          state = STATE_ACTIVE;

          // start read time capture
          last_read_t = millis();

          // reset the trip stats
          // Moved to TRIP_STATS_init, called in init()
          //  to save stats until power cycled
          //TRIP_STATS_reset();

          #ifdef DEBUG
            DebugSerial.println ("To state: ACTIVE");
          #endif
        }
        else
        {
          #ifdef DEBUG
            DebugSerial.println ("Temp not yet valid");
          #endif
        }
      }

      // initiate a read for next time
      if (read_flag)
      {
        // note: don't clear the read_flag here as it is used & cleared below for BMS data

        // Request data from motor controller via UART
        VotolSerial.write (VOTOL_Request_Local, sizeof (VOTOL_Request_Local));

        // immediately read / clear the buffer
        // as the 'CAN' converter echos the TX packet back to RX
        // Flush instead of reading back to avoid hanging on corrupted packets
        //VotolSerial.readBytes (VOTOL_Buffer, sizeof (VOTOL_Request_Local));
        VOTOL_flush_rx ();

        #ifdef DEBUG
          DebugSerial.println ("Votol request sent");
        #endif
      }

    break;

    // BMS and Votol actively responding
    case STATE_ACTIVE:

      // detect Votol timeout ane return to IDLE state
      // (e.g. controller is switched off)
      if (read_flag && !update_flags.flags.votol)
      {

        if (++votol_timeout_cnt >= T_VOTOL_TIMEOUT)
        {
          // clear the VOTOL data
          // memcpy (&VOTOL_Response.data, &VOTOL_Buffer_init, sizeof (VOTOL_Buffer_init)); // not needed with IDLE state
          votol_timeout_cnt = 0; // start counting again, when new valid data arrives

          // back to IDLE state
          state = STATE_IDLE;

          #ifdef DEBUG
            DebugSerial.println("To state: IDLE");
          #endif
        }
        else
        {
          #ifdef DEBUG
            DebugSerial.print ("Votol timeout count: ");
            DebugSerial.println (votol_timeout_cnt);
          #endif        
        }
      }

      // valid data this time, clear the timeout_count
      if (update_flags.flags.votol)
      {
        votol_timeout_cnt = 0;

        // update the stats
        read_t = millis() - last_read_t;
        last_read_t = millis();
        uint16_t rpm = VOTOL_get_rpm (&VOTOL_Response.resp);

        trip_stats.distance_mm += WHEEL_CIRC * rpm * read_t / 60000;
        trip_stats.watt_s_x100 += VOTOL_get_volts (&VOTOL_Response.resp) * VOTOL_get_amps (&VOTOL_Response.resp) * read_t / 1000;

        #ifdef DEBUG
            uint16_t avg_speed = TRIP_STATS_get_avg_speed ();
            DebugSerial.printf ("Distance: %d.%d\r\n", trip_stats.distance_mm / 1000000, trip_stats.distance_mm % 10);
            DebugSerial.printf ("Watt seconds: %d\r\n", trip_stats.watt_s_x100 / 100);
            DebugSerial.printf ("Current speed x10: %d\r\n", WHEEL_CIRC * rpm * 36 / 60000);
            DebugSerial.printf ("Avg speed: %d.%d\r\n", avg_speed / 10, avg_speed % 10);
            DebugSerial.printf ("Trip time: %d:%02d:%02d\r\n", trip_stats.trip_time.getHours(), trip_stats.trip_time.getMinutes(), trip_stats.trip_time.getSeconds());
        #endif
      }

      // initiate a read for next time
      if (read_flag)
      {
        // note: don't clear the read_flag here as it is used & cleared below for BMS data

        // Request data from motor controller via UART
        VotolSerial.write (VOTOL_Request_Local, sizeof (VOTOL_Request_Local));

        // immediately read / clear the buffer
        // as the 'CAN' converter echos the TX packet back to RX
        // Flush instead of reading back to avoid hanging on corrupted packets
        //VotolSerial.readBytes (VOTOL_Buffer, sizeof (VOTOL_Request_Local));
        VOTOL_flush_rx ();

        #ifdef DEBUG
          DebugSerial.println ("Votol request sent");
        #endif
      }

      // All data updated
      // Dash needs to be updated
      // Also check for charging
      if ((update_flags.all_flags & ALL_UPDATED) == ALL_UPDATED)
      {
        update_flags.all_flags = 0; // reset update flags for next time
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

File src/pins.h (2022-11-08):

#ifndef PINS_H
#define PINS_H

#define DEBUG_USART     USART1  // TX1: PA9 RX1: PA10
#define VOTOL_USART     USART3  // TX3: PB10 RX3: PB11

#define CAN_REMAP        2   // CAN_RX mapped to PB8, CAN_TX mapped to PB9 (not available on 36-pin package)

#define OLED_DC_1       PB6
#define OLED_CS_1       PB5 
#define OLED_RESET_1    PB7

#define OLED_DC_2       PA4
#define OLED_CS_2       PA2  
#define OLED_RESET_2    PA3

#define LIGHTS_IN       PB12
#define TURN_L_IN       PA12
#define TURN_R_IN       PA11
#define BRAKE_IN        PB13

#define MODE_1_IN       PA8
#define MODE_2_IN       PA15

#define TURN_L_OUT      PB1
#define TURN_R_OUT      PB0
#define TURN_IND_OUT    PB3
#define GAUGE_PWM       PB14

#endif

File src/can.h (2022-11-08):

// Adapted from
// https://github.com/nopnop2002/Arduino-STM32-CAN
//
  
#ifndef CAN_H_INCLUDED
#define CAN_H_INCLUDED

#include <Arduino.h>

#define CAN_DEBUG 0

#define STM32_CAN_TIR_TXRQ              (1U << 0U)  // Bit 0: Transmit Mailbox Request
#define STM32_CAN_RIR_RTR               (1U << 1U)  // Bit 1: Remote Transmission Request
#define STM32_CAN_RIR_IDE               (1U << 2U)  // Bit 2: Identifier Extension
#define STM32_CAN_TIR_RTR               (1U << 1U)  // Bit 1: Remote Transmission Request
#define STM32_CAN_TIR_IDE               (1U << 2U)  // Bit 2: Identifier Extension

#define CAN_EXT_ID_MASK                 0x1FFFFFFFU
#define CAN_STD_ID_MASK                 0x000007FFU
 
/* Symbolic names for bit rate of CAN message                                */
typedef enum {CAN_50KBPS, CAN_100KBPS, CAN_125KBPS, CAN_250KBPS, CAN_500KBPS, CAN_1000KBPS} BITRATE;

/* Symbolic names for formats of CAN message                                 */
typedef enum {STANDARD_FORMAT = 0, EXTENDED_FORMAT} CAN_FORMAT;

/* Symbolic names for type of CAN message                                    */
typedef enum {DATA_FRAME = 0, REMOTE_FRAME}         CAN_FRAME;

typedef struct
{
  uint32_t id;        /* 29 bit identifier                               */
  uint8_t  data[8];   /* Data field                                      */
  uint8_t  len;       /* Length of data field in bytes                   */
  uint8_t  ch;        /* Object channel(Not use)                         */
  uint8_t  format;    /* 0 - STANDARD, 1- EXTENDED IDENTIFIER            */
  uint8_t  type;      /* 0 - DATA FRAME, 1 - REMOTE FRAME                */
} CAN_msg_t;

typedef const struct
{
  uint8_t TS2;
  uint8_t TS1;
  uint8_t BRP;
} CAN_bit_timing_config_t;


/**
 * Print registers.
*/ 
void printRegister(char * buf, uint32_t reg);

/**
 * Initializes the CAN filter registers.
 *
 * @preconditions   - This register can be written only when the filter initialization mode is set (FINIT=1) in the CAN_FMR register.
 * @params: index   - Specified filter index. index 27:14 are available in connectivity line devices only.
 * @params: scale   - Select filter scale.
 *                    0: Dual 16-bit scale configuration
 *                    1: Single 32-bit scale configuration
 * @params: mode    - Select filter mode.
 *                    0: Two 32-bit registers of filter bank x are in Identifier Mask mode
 *                    1: Two 32-bit registers of filter bank x are in Identifier List mode
 * @params: fifo    - Select filter assigned.
 *                    0: Filter assigned to FIFO 0
 *                    1: Filter assigned to FIFO 1
 * @params: bank1   - Filter bank register 1
 * @params: bank2   - Filter bank register 2
 *
 */
void CANSetFilter(uint8_t index, uint8_t scale, uint8_t mode, uint8_t fifo, uint32_t bank1, uint32_t bank2);

/**
 * Initializes the CAN controller with specified bit rate.
 *
 * @params: bitrate - Specified bitrate. If this value is not one of the defined constants, bit rate will be defaulted to 125KBS
 * @params: remap   - Select CAN port. 
 *                    =0:CAN_RX mapped to PA11, CAN_TX mapped to PA12
 *                    =1:Not used
 *                    =2:CAN_RX mapped to PB8, CAN_TX mapped to PB9 (not available on 36-pin package)
 *                    =3:CAN_RX mapped to PD0, CAN_TX mapped to PD1 (available on 100-pin and 144-pin package)
 *
 */
bool CANInit(BITRATE bitrate, int remap);

/**
 * Decodes CAN messages from the data registers and populates a 
 * CAN message struct with the data fields.
 * 
 * @preconditions A valid CAN message is received
 * @params CAN_rx_msg - CAN message structure for reception
 * 
 */
void CANReceive(CAN_msg_t* CAN_rx_msg);
 
/**
 * Encodes CAN messages using the CAN message struct and populates the 
 * data registers with the sent.
 * 
 * @params CAN_tx_msg - CAN message structure for transmission
 * 
 */
void CANSend(CAN_msg_t* CAN_tx_msg);

 /**
 * Returns whether there are CAN messages available.
 *
 * @returns If pending CAN messages are in the CAN controller
 *
 */
uint8_t CANMsgAvail(void);


#endif

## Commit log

2022-11-08 Fixed string buffer size; renamed avg_speed_x10
    [display.cpp, main.cpp]
2022-11-20 Moved Votol and BMS globals to modules
2022-11-21 Fixed Votol startup bug, new flush_rx function
    [main.cpp]
2022-11-21 Fixed Votol startup bug; flush_rx function
    [votol_em.cpp]
2022-11-21 Mode switching, disable interrupts in debounce
2022-11-22 Fixed mode switch logic; don't disable interrupts
    [display.cpp]
2023-01-17 Fix amps display for small values
    [display.cpp]
2023-01-20 Added Hardware folder and updated Readme
    [CAN_controller_main_dash.brd, CAN_controller_main_dash.sch, CAN_controller_rear_lighting.brd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]
2023-01-20 Moved rear lighting Hardware files to own repo
    [CAN_controller_rear_lighting.brd, CAN_controller_rear_lighting.sch]
2023-03-12 Attempt to fix wh/km bug (distance_mm to int32)
    [display.cpp]
2023-03-12 Clear trip stats only on power cycle
2026-02-21 Added fault codes to voltol_em.h

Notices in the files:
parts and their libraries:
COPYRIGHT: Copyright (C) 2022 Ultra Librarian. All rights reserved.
